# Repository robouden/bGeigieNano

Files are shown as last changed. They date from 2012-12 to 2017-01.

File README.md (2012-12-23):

# Welcome to bGeigie Nano Kit project

This is a lighter version of the bGeigie Mini which is meant to fit in a Pelican Micro Case 1010.

# Requirements
* [Arduino Fio][3]
* [OpenLog][1]
* Adafruit [Ultimate GPS][7]
* [LND-7317][4] geiger pancake with Medcom iRover HV board
* [Monochrome 128x32][2] OLED screen
* 3.7V 1300mAh Lithium battery
* [Pelican 1010][9] micro-case

# Assembly

bGeigieNano

## Pins assignment

| Arduino Fio pin | Target pin |
| :---: | :---: |
| VCC | VCC or Vin pin of the GPS, OpenLog, OLED and iRover (3.3v)|
| GND | GND pin of the GPS, OpenLog, OLED and iRover |
| D2 | pulse pin from the iRover |
| D3 | OLED RST pin |
| D4 | OLED CS pin |
| D5 | OLED DC pin |
| D6 | OLED Data pin |
| D7 | OLED Clk pin |
| D8 | TX pin of the GPS |
| D9 | RX pin of the GPS |
| D10 | TX pin of the OpenLog |
| D11 | RX pin of the OpenLog |
| D12 | GRN pin of the OpenLog |

# Power consumption

* **Fio**: 0.045mA sleep, 6mA at run time
* **OpenLog**: 2mA idle, 6mA at maximum recording rate
* **Adafruit Ultimate GPS**: 25mA acquisition, 20mA tracking
* **Monochrome OLED 128x32 0.91"**: 4mA 50% turn-on, 7.8mA 100% turn-on

## Estimation
The total current used at run time can be estimated around 36mA (= 6+6+20+4) per second which will result in a consumption of 0.01mAh (= 36mA/3600). So
the total log duration if using a battery of 1300mAh will be (1300/.01)/3600 = 36.11 = **36h06m**

## Summary table

| Battery capacity (mAh) | Estimated log duration (days hh:mm) |
| :---: | :---: |
| 1300 | 1d 12:06 |
| 2600 |  3d 00:13 |
| 6600 |  7d 15:19 |

# Build process
## Using the Makefile
    export ARDUINODIR=/home/geigie/arduino-1.0.1/
    export SERIALDEV=/dev/ttyUSB0
    export BOARD=fio
    cp -r libraries /home/geigie/arduino-1.0.1/
    make
    make upload

## Using the prebuilt image
You can use directly the prebuilt image to flash the Arduino Fio. Here is an example with Arduino Fio connected to ttyUSB0:

    /usr/bin/avrdude -DV -p atmega328p -P /dev/ttyUSB0 -c arduino -b 57600 -U flash:w:bGeigieNano.hex:i

# Usage
Once powered on the bGeigieNano will initiliaze a new log file on the SD card, setup the GPS and start counting the CPM.

# Sample log

    # NEW LOG
    # format=1.0.0nano
    $BNRDD,204,2012-09-20T16:53:58Z,776,63,33895,A,5641.7788,N,1411.8820,E,9861.20,A,109,9*46
    $BNRDD,204,2012-09-20T16:54:03Z,771,61,33956,A,5642.2047,N,1412.9433,E,9862.60,A,109,9*4D
    $BNRDD,204,2012-09-20T16:54:08Z,773,70,34026,A,5642.6305,N,1414.0053,E,9865.00,A,109,9*40
    $BNRDD,204,2012-09-20T16:54:13Z,768,59,34085,A,5643.0562,N,1415.0662,E,9866.80,A,108,9*4D
    $BNRDD,204,2012-09-20T16:54:18Z,765,59,34144,A,5643.4820,N,1416.1277,E,9868.10,A,108,9*4D
    $BNRDD,204,2012-09-20T16:54:23Z,776,70,34214,A,5643.9077,N,1417.1884,E,9870.40,A,90,10*4E
    $BNRDD,204,2012-09-20T16:54:28Z,790,69,34283,A,5644.3330,N,1418.2491,E,9871.30,A,90,10*44
    $BNRDD,204,2012-09-20T16:54:33Z,792,77,34360,A,5644.7576,N,1419.3115,E,9871.40,A,90,10*41
    $BNRDD,204,2012-09-20T16:54:38Z,800,73,34433,A,5645.1819,N,1420.3749,E,9872.60,A,90,10*4C
    $BNRDD,204,2012-09-20T16:54:43Z,784,57,34490,A,5645.6060,N,1421.4371,E,9873.10,A,89,10*4A
    $BNRDD,204,2012-09-20T16:54:48Z,787,58,34548,A,5646.0298,N,1422.4998,E,9874.10,A,89,10*40
    $BNRDD,204,2012-09-20T16:54:53Z,792,76,34624,A,5646.4534,N,1423.5620,E,9874.80,A,98,9*73
    $BNRDD,204,2012-09-20T16:54:58Z,804,75,34699,A,5646.8769,N,1424.6242,E,9874.30,A,98,9*74
    $BNRDD,204,2012-09-20T16:55:03Z,808,65,34764,A,5647.3011,N,1425.6873,E,9877.10,A,98,9*7F
    $BNRDD,204,2012-09-20T16:55:08Z,793,55,34819,A,5647.7236,N,1426.7514,E,9876.30,A,89,10*49
    $BNRDD,204,2012-09-20T16:55:13Z,799,65,34884,A,5648.1464,N,1427.8159,E,9876.10,A,98,9*7F
    $BNRDD,204,2012-09-20T16:55:18Z,795,55,34939,A,5648.5688,N,1428.8810,E,9877.80,A,98,9*7B
    $BNRDD,204,2012-09-20T16:55:23Z,774,49,34988,A,5648.9898,N,1429.9472,E,9878.50,A,85,10*46
    $BNRDD,204,2012-09-20T16:55:28Z,768,63,35051,A,5649.4098,N,1431.0137,E,9877.40,A,224,8*4A
    $BNRDD,204,2012-09-20T16:55:33Z,754,63,35114,A,5649.8297,N,1432.0798,E,9876.30,A,223,8*4F
    $BNRDD,204,2012-09-20T16:55:38Z,752,71,35185,A,5650.2496,N,1433.1447,E,9873.20,A,106,9*4C
    $BNRDD,204,2012-09-20T16:55:43Z,753,58,35243,A,5650.6698,N,1434.2092,E,9871.30,A,106,9*40
    $BNRDD,204,2012-09-20T16:55:48Z,765,70,35313,A,5651.0904,N,1435.2737,E,9869.50,A,106,9*4B

# Notes
## OpenLog config

The OpenLog should start listening at 9600bps and in Command mode. Here is the content of the CONFIG.TXT file you have to create on the microSD card:

    9600,26,3,2

## SoftwareSerial update

To make sure all of the NMEA sentences can be received correctly, we will need to update the _SS_MAX_RX_BUFF definition from arduino-1.0.1/libraries/SoftwareSerial/SoftwareSerial.h header file. Here is the modification:

    //#define _SS_MAX_RX_BUFF 64 // RX buffer size -- Old Value is 64
    #define _SS_MAX_RX_BUFF 128 // RX buffer size for TinyGPS

# Licenses
 * [InterruptHandler and bGeigieMini code][5] - Copyright (c) 2011, Robin Scheibler aka FakuFaku
 * [TinyGPS][6] - Copyright (C) 2008-2012 Mikal Hart
 * bGeigieNano - Copyright (c) 2012, Lionel Bergeret
 * [Makefile][8] - Copyright (c) 2012, Tim Marston

  [1]: https://github.com/sparkfun/OpenLog "OpenLog"
  [2]: https://www.adafruit.com/products/661 "Monochrome 128x32 OLED"
  [3]: https://www.sparkfun.com/products/10116 "Arduino Fio"
  [4]: http://www.lndinc.com/products/17/ "LND-7317"
  [5]: https://github.com/fakufaku/SafecastBGeigie-firmware "SafecastBGeigie-firmware"
  [6]: http://arduiniana.org/libraries/tinygps/ "TinyGPS"
  [7]: https://www.adafruit.com/products/746 "Ultimate GPS"
  [8]: http://ed.am/dev/make/arduino-mk "Arduino Makefile"
  [9]: http://www.pelican.com/cases_detail.php?Case=1010 "Pelican 1010"

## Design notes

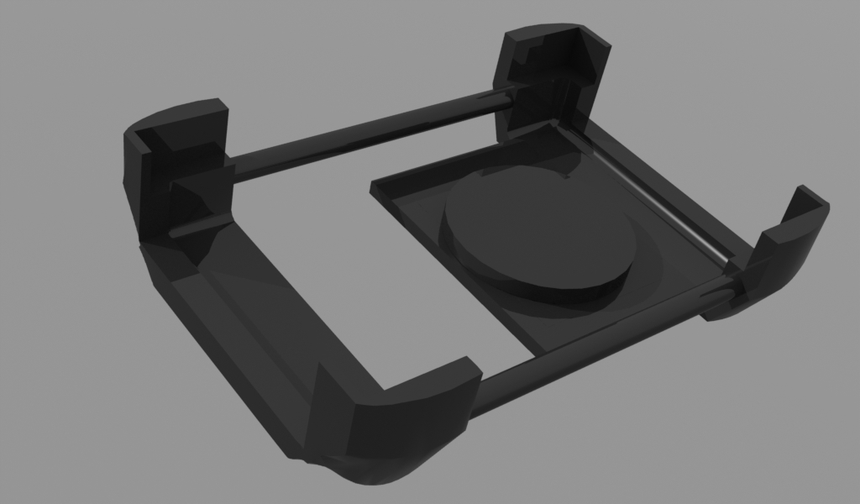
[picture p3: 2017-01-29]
sketchup files/wireless charger.JPG

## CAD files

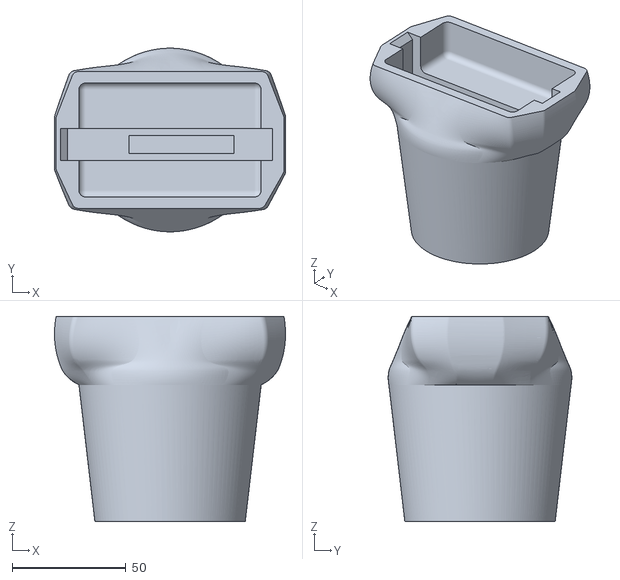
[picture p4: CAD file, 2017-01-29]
sketchup files/PelicanHolder5.stl
101.4 x 80.6 x 90.0

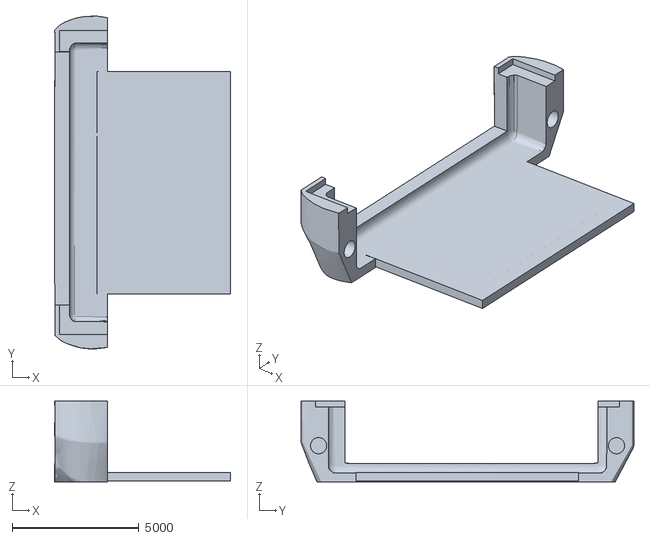
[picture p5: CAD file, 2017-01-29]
sketchup files/wireless charger teensy bgeigie.STL
6935.8 x 13111.0 x 3190.0

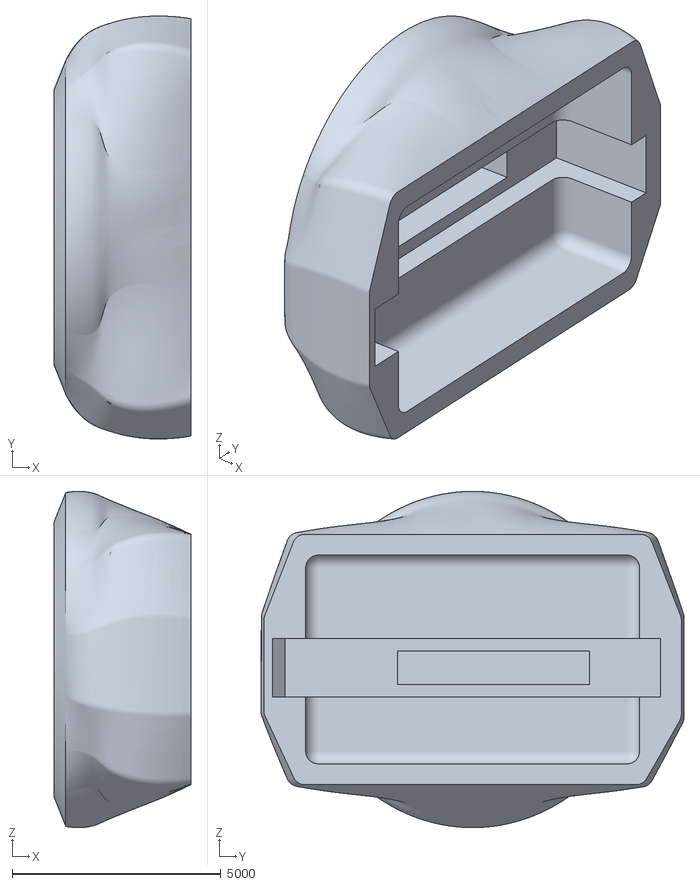
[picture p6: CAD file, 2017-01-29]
sketchup files/cup holder low bottom.STL
3280.0 x 10135.9 x 8058.9

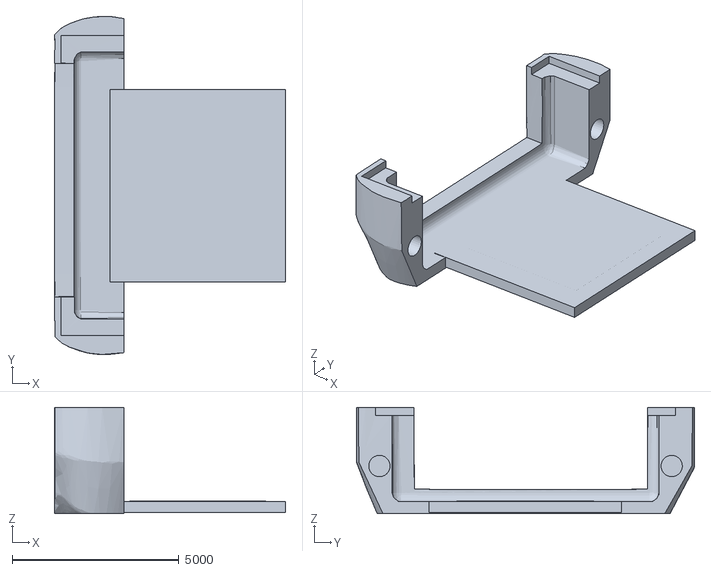
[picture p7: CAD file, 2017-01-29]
sketchup files/cup holder half cut left new.STL
6935.8 x 10131.0 x 3190.0

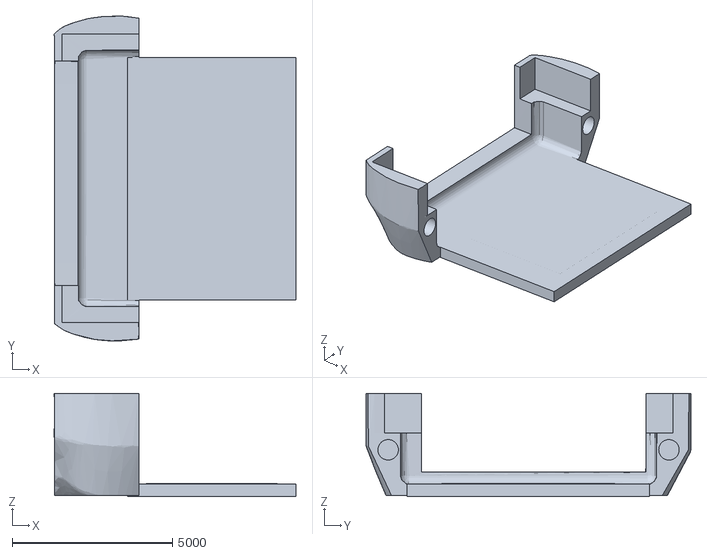
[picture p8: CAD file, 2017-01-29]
sketchup files/cup holder half cut 4.STL
7549.3 x 10131.0 x 3220.0

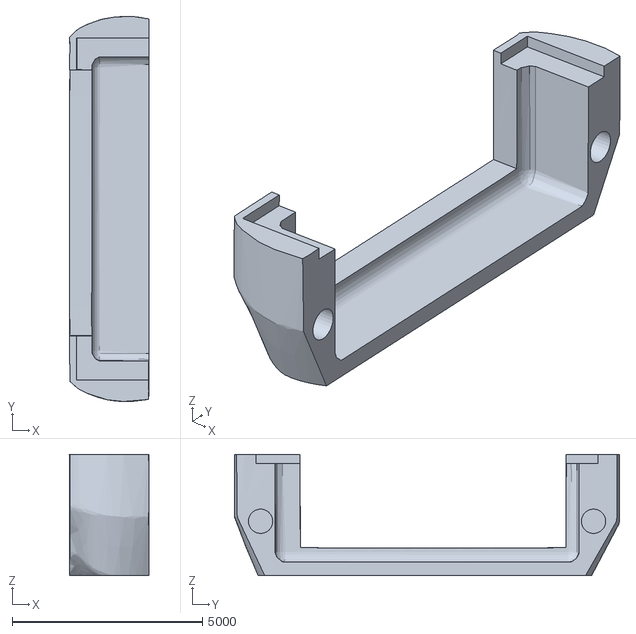
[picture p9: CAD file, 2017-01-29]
sketchup files/cup holder half cut 5.STL
2093.1 x 10131.0 x 3190.0

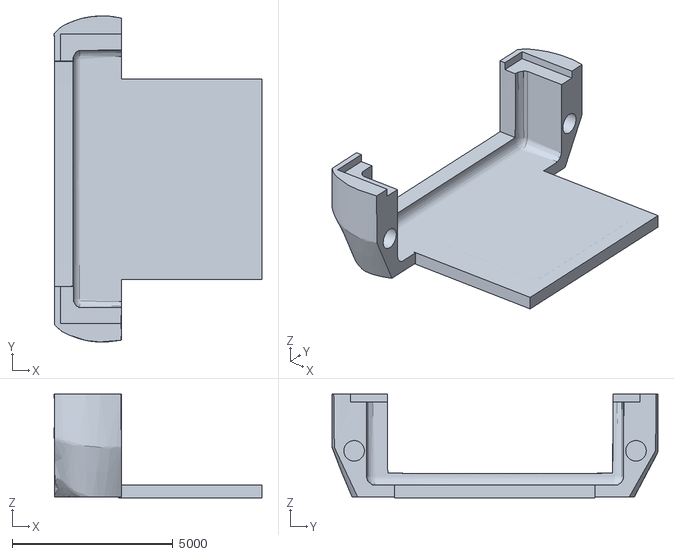
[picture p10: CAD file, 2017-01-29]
sketchup files/cup holder half cut 6.STL
6462.7 x 10131.0 x 3220.0

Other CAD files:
sketchup files/cup holder half cut.STL
sketchup files/cup holder.STL
sketchup files/Wireless charger EJ.skp
sketchup files/Wireless charger EJ~.skp
sketchup files/cup holder.obj

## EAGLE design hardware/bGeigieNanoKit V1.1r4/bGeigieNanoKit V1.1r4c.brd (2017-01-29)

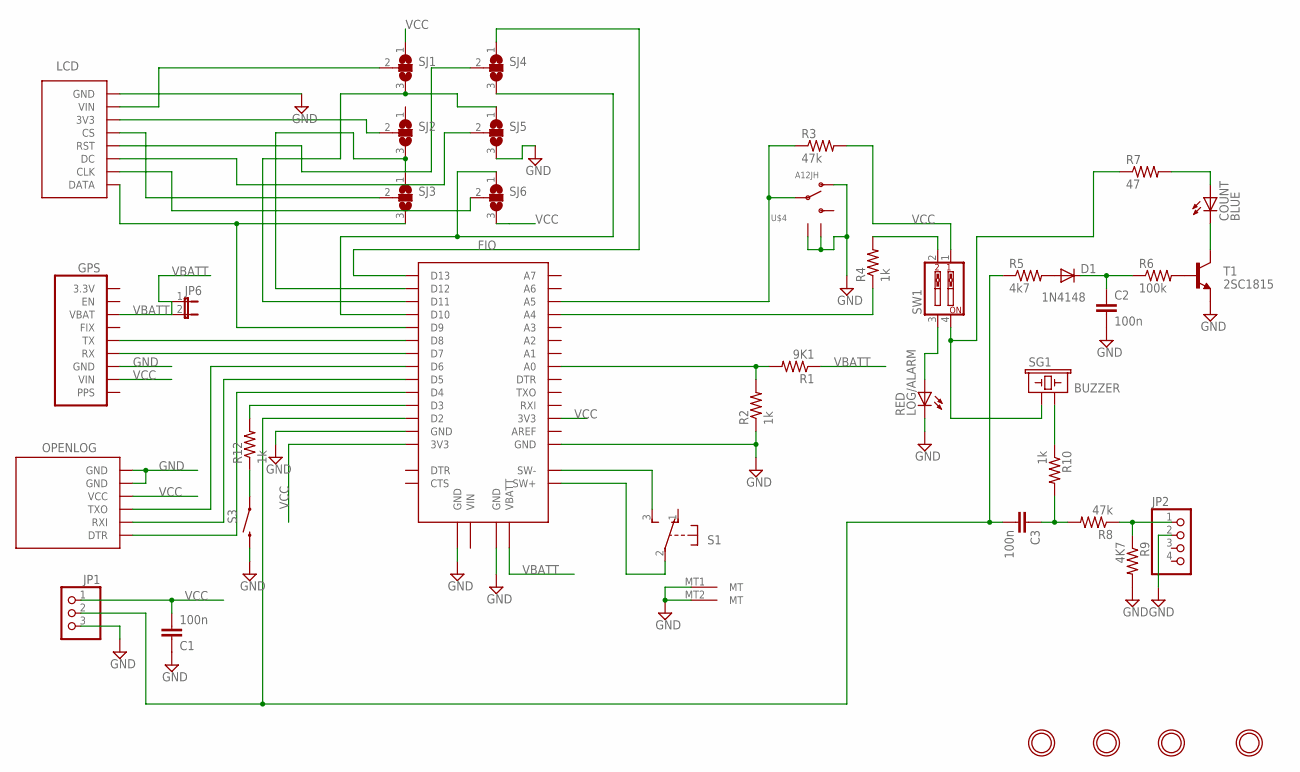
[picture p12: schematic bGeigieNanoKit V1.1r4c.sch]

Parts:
C1, C2, C3: 100n; C025-024X044
COUNT: BLUE; LED3MM
D1: 1N4148; DO35-7
FIO: FIO_SOCKETBOT; FIO_V23_SOCKET_BOT
GPS: ULTIMATE_GPSTOP; ULTIMATE_GPS_V3_TOP
JP1: PINHD-1X3/90; 1X03/90
JP2: HEADER-1X4ROUND; 1X04_ROUND
JP6: JUMPER-2SMD-NC; SJ_2S
LCD: SSD1306_128X64_V2_LCD1.3IN_LEVER; SSD1306_128X64_1.3IN_LCD_LEVER
LOG/ALARM: RED; LED3MM
OPENLOG: OPENLOG
R1: 9K1; 0207/10
R2, R4, R10, R12: 1k; 0207/10
R3, R8: 47k; 0207/10
R5: 4k7; 0207/10
R6: 100k; 0207/10
R7: 47; 0207/10
R9: 4K7; 0207/10
S1: S1; EG1206
S3: SWITCH-MOMENTARY-2PTH; TACTILE-PTH
SG1: BUZZER; BUZZER-12MM
SJ1, SJ2, SJ3, SJ4, SJ5, SJ6: SJ2W; SJ_2
SW1: SW_DIP-2; EDG-02
T1: 2SC1815; TO92-ECB
U$4: A12JH; A12AH
U$6, U$7, U$8, U$9: MOUNTINGHOLE3.0THIN; MOUNTINGHOLE_3.0_PLATEDTHIN

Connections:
GND: C1.1, C2.2, FIO.JP1$2 (GND), FIO.JP2$1 (GND), FIO.JP5$1 (GND), FIO.JP6$1 (GND), GPS.JP1$3 (GND), GPS.U$8$P$1 (GND), GPS.U$9$P$1 (GND), JP1.3, JP2.2, LCD.JP1$8 (GND), LCD.U$23$P$1 (GND), LCD.U$26$P$1 (GND), LOG/ALARM.K (C), OPENLOG.JP1$5 (GND), OPENLOG.JP1$6 (GND), R2.1, R9.2, S1.MT1 (MT), S1.MT2 (MT), S3.3 (2), SJ5.3, T1.E, U$4.P$1, U$4.P$4 (GND), U$4.P$5 (GND)
unnamed: FIO.JP1$10 (D9), LCD.JP1$1 (DATA), SJ3.3
unnamed: FIO.JP1$11 (D10), SJ4.3, SJ6.1
unnamed: FIO.JP1$12 (D11), SJ1.3, SJ5.1
unnamed: FIO.JP1$13 (D12), SJ2.3, SJ3.1
unnamed: FIO.JP1$14 (D13), SJ4.1
unnamed: FIO.JP1$9 (D8), GPS.JP1$5 (TX)
unnamed: FIO.JP1$8 (D7), GPS.JP1$4 (RX)
unnamed: FIO.JP1$7 (D6), OPENLOG.JP1$3 (TXO)
unnamed: FIO.JP1$6 (D5), OPENLOG.JP1$2 (RXI)
unnamed: FIO.JP1$5 (D4), OPENLOG.JP1$1 (DTR)
unnamed: FIO.JP5$7 (A0), R1.2, R2.2
unnamed: FIO.JP7$2 (SW+), S1.2
unnamed: FIO.JP7$1 (SW-), S1.3 (S)
unnamed: FIO.JP5$12 (A5), R3.1, U$4.P$2
unnamed: LOG/ALARM.A, SW1.3
unnamed: R4.2, SW1.2
unnamed: C3.2, FIO.JP1$3 (D2), JP1.2, R5.1
unnamed: COUNT.A, R7.2
unnamed: R12.1, S3.1
unnamed: COUNT.K (C), T1.C
unnamed: R10.1, SG1.- (2)
unnamed: C3.1, R8.2, R10.2
unnamed: JP2.1, R8.1, R9.1
unnamed: D1.A, R5.2
unnamed: C2.1, D1.C, R6.1
unnamed: R6.2, T1.B
unnamed: FIO.JP1$4 (D3), R12.2
unnamed: LCD.JP1$7 (VIN), SJ1.2
unnamed: R7.1, SG1.+ (1), SW1.4
unnamed: FIO.JP5$11 (A4), R4.1
unnamed: LCD.JP1$6 (3V3), SJ2.2
unnamed: LCD.JP1$5 (CS), SJ3.2
unnamed: LCD.JP1$4 (RST), SJ4.2
unnamed: LCD.JP1$3 (DC), SJ5.2
unnamed: LCD.JP1$2 (CLK), SJ6.2
VBATT: FIO.JP2$2 (VBATT), GPS.JP1$7 (VBAT), JP6.1, JP6.2, R1.1
VCC: C1.2, FIO.JP1$1 (3V3), FIO.JP5$3 (3V3), GPS.JP1$2 (VIN), JP1.1, OPENLOG.JP1$4 (VCC), R3.2, SJ1.1, SJ6.3, SW1.1

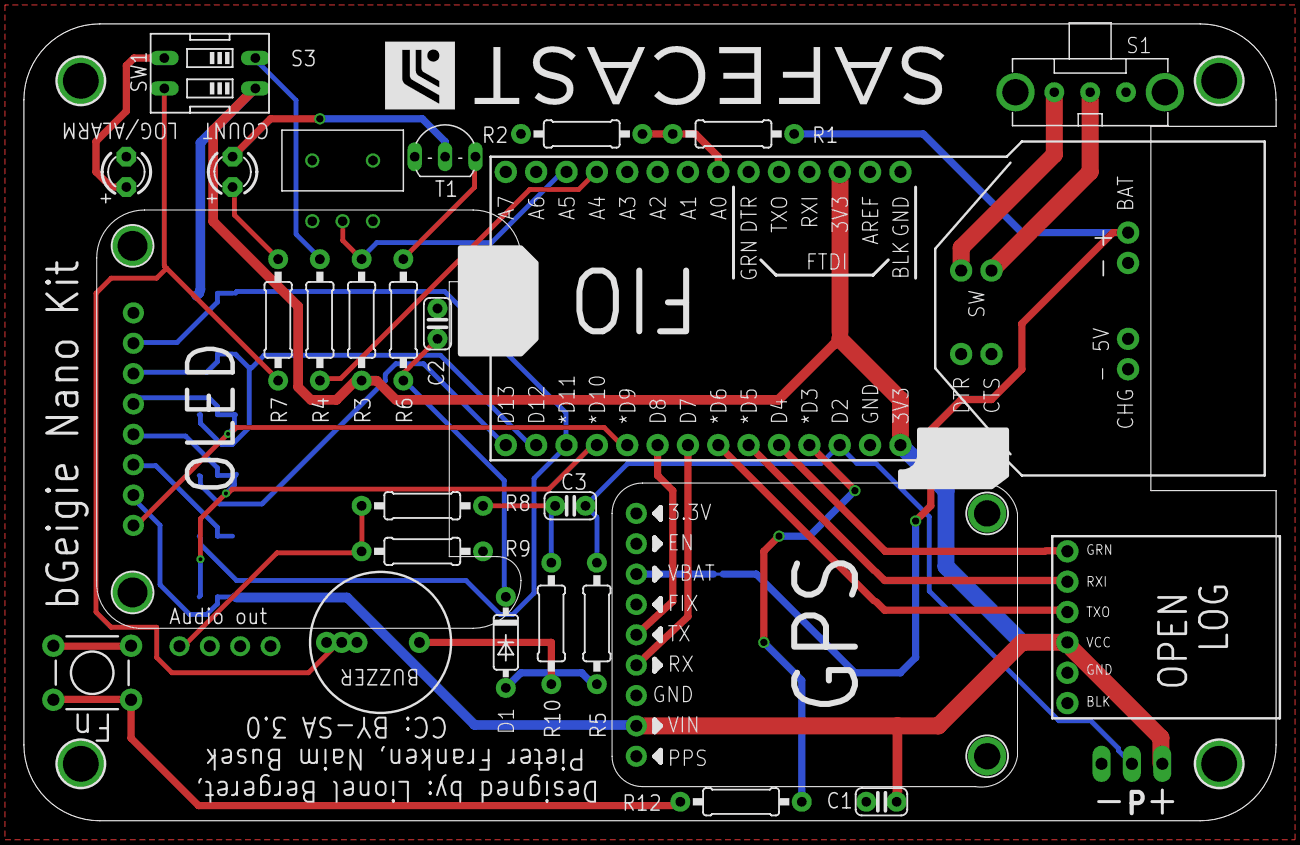
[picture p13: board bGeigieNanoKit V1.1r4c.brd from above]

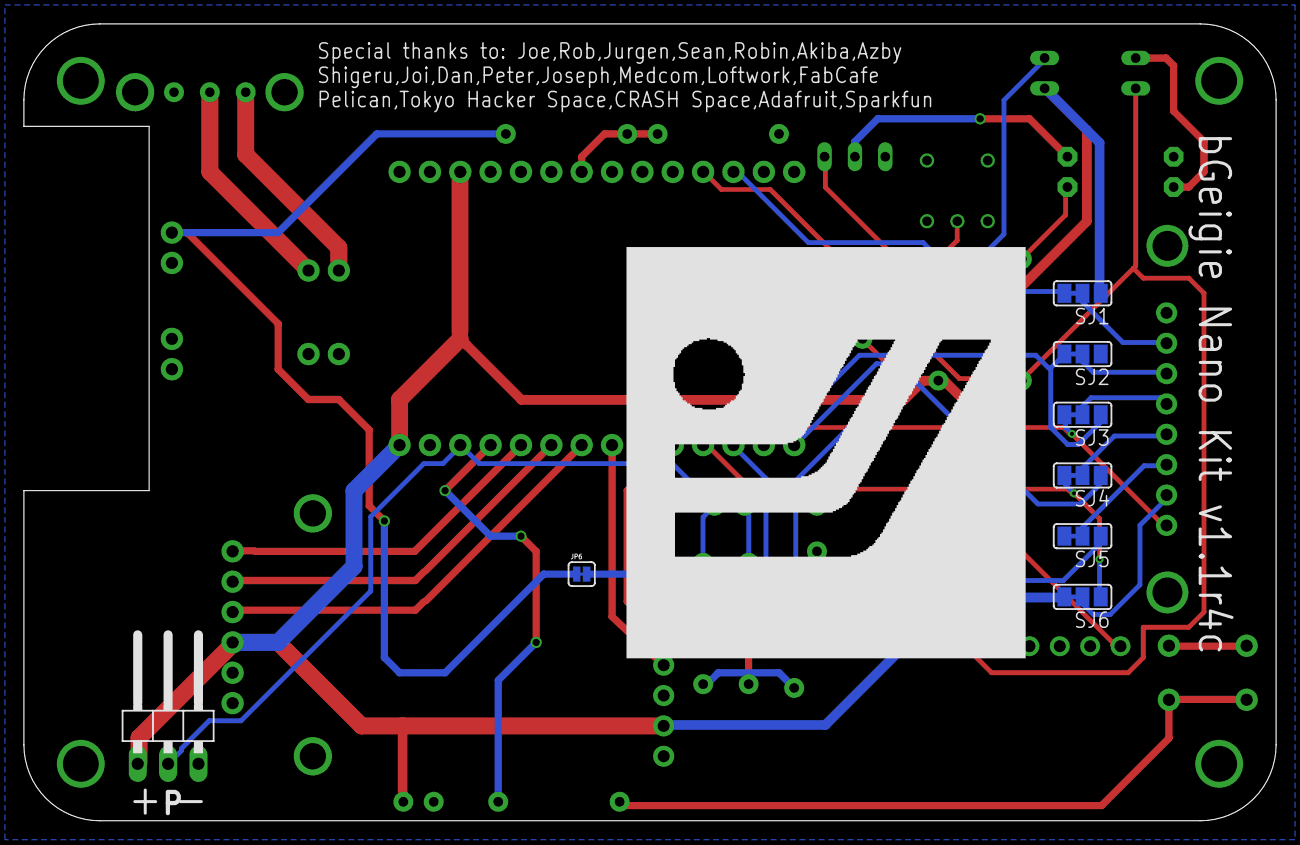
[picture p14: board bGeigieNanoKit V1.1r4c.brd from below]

Board: 2 copper layers, 104.8 x 66.7 mm, 42 parts (10 on the bottom side), 38 nets.

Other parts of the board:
U$1: SAFECAST_LOGO4
U$5: SAFECAST_LOGO2

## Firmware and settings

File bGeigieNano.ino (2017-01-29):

/*
   The bGeigie-nano
   A device for car-borne radiation measurement (aka Radiation War-driving).

   Copyright (c) 2012, Lionel Bergeret
   Copyright (c) 2011, Robin Scheibler aka FakuFaku, Christopher Wang aka Akiba
   All rights reserved.

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
   THIS SOFTWARE IS PROVIDED BY THE COPYRIGHT HOLDERS AND CONTRIBUTORS "AS IS" AND
   ANY EXPRESS OR IMPLIED WARRANTIES, INCLUDING, BUT NOT LIMITED TO, THE IMPLIED
   WARRANTIES OF MERCHANTABILITY AND FITNESS FOR A PARTICULAR PURPOSE ARE
   DISCLAIMED. IN NO EVENT SHALL <COPYRIGHT HOLDER> BE LIABLE FOR ANY
   DIRECT, INDIRECT, INCIDENTAL, SPECIAL, EXEMPLARY, OR CONSEQUENTIAL DAMAGES
   (INCLUDING, BUT NOT LIMITED TO, PROCUREMENT OF SUBSTITUTE GOODS OR SERVICES;
   LOSS OF USE, DATA, OR PROFITS; OR BUSINESS INTERRUPTION) HOWEVER CAUSED AND
   ON ANY THEORY OF LIABILITY, WHETHER IN CONTRACT, STRICT LIABILITY, OR TORT
   (INCLUDING NEGLIGENCE OR OTHERWISE) ARISING IN ANY WAY OUT OF THE USE OF THIS
   SOFTWARE, EVEN IF ADVISED OF THE POSSIBILITY OF SUCH DAMAGE.
*/

#include <limits.h>
#include <SoftwareSerial.h>
#include <math.h>
#include <stdlib.h>
#include <avr/wdt.h>
#include <EEPROM.h>
#include "TinyGPS.h"

#include "NanoSetup.h"
#include "NanoConfig.h"
#include "NanoDebug.h"

// OLED settings --------------------------------------------------------------
#if ENABLE_SSD1306
#include <Wire.h>
#include <Adafruit_GFX.h>
#include <Adafruit_SSD1306.h>

#ifdef OLED_SPI_MODE
Adafruit_SSD1306 display(OLED_DATA, OLED_CLK, OLED_DC, OLED_RESET, OLED_CS);
#else
Adafruit_SSD1306 display(OLED_RESET);
#endif

#if (SSD1306_LCDHEIGHT != 32)
#error("Height incorrect, please fix Adafruit_SSD1306.h!");
#endif

// For distance computation
bool gps_fix_first = true;
float gps_last_lon = 0, gps_last_lat = 0;
unsigned long int gps_distance = 0;
#endif

// Geiger settings ------------------------------------------------------------
#define TIME_INTERVAL 5000
#define LINE_SZ 100
#define BUFFER_SZ 12
#define STRBUFFER_SZ 32
#define NX 12
#define AVAILABLE 'A'  // indicates geiger data are ready (available)
#define VOID      'V'  // indicates geiger data not ready (void)

// log file headers
#define LOGFILE_HEADER "# NEW LOG\n# format="
char logfile_name[13];  // placeholder for filename
bool logfile_ready = false;

// geiger statistics
unsigned long shift_reg[NX] = {0};
unsigned long reg_index = 0;
unsigned long total_count = 0;
unsigned long max_count = 0;
unsigned long uptime = 0;
int str_count = 0;
char geiger_status = VOID;

// the line buffer for serial receive and send
static char line[LINE_SZ];
static char strbuffer[STRBUFFER_SZ];

// Pulse counter --------------------------------------------------------------
#if ENABLE_HARDWARE_COUNTER
// Hardware counter
#include "HardwareCounter.h"
HardwareCounter hwc(HARDWARE_COUNTER_TIMER1, TIME_INTERVAL);
#else
// Interrupt counter
#include "InterruptCounter.h"
#endif

#if ENABLE_HARDWARE_COUNTER
#if ENABLE_SLEEPMODE
#define IS_READY (1)
#else
#define IS_READY (hwc.available())
#endif
#else
#define IS_READY (interruptCounterAvailable())
#endif

// OpenLog settings -----------------------------------------------------------
#if ENABLE_OPENLOG
#define OPENLOG_RETRY 200
SoftwareSerial OpenLog(OPENLOG_RX_PIN, OPENLOG_TX_PIN);
static const int resetOpenLog = OPENLOG_RST_PIN;
#endif
bool openlog_ready = false;

// Gps settings ------------------------------------------------------------
TinyGPS gps(true);
#define GPS_INTERVAL 1000
char gps_status = VOID;

#if ENABLE_SOFTGPS
SoftwareSerial gpsSerial(GPS_RX_PIN, GPS_TX_PIN);
#endif

// Gps data buffers
static char lat[BUFFER_SZ];
static char lon[BUFFER_SZ];

// MTK33x9 chipset
#define PMTK_SET_NMEA_UPDATE_1HZ "$PMTK220,1000*1F"
#define PMTK_SET_NMEA_OUTPUT_ALLDATA "$PMTK314,1,1,1,1,1,1,0,0,0,0,0,0,0,0,0,0,0,0,0*28"
#define PMTK_SET_NMEA_OUTPUT_RMCGGA "$PMTK314,0,1,0,1,0,0,0,0,0,0,0,0,0,0,0,0,0,0,0*28"
#define SBAS_ENABLE "$PMTK313,1*2E\r\n"
#define DGPS_WAAS_ON "$PMTK301,2*2E\r\n"

#if ENABLE_STATIC_GPS
#include <avr/pgmspace.h>
// GPS test sentences
char strGPRMC[] PROGMEM = "$GPRMC,201547.000,A,3014.5527,N,09749.5808,W,0.24,163.05,040109,,*1A";
char strGPGGA[] PROGMEM = "$GPGGA,201548.000,3014.5529,N,09749.5808,W,1,07,1.5,225.6,M,-22.5,M,18.8,0000*78";
char *teststrs[2] = {strGPRMC, strGPGGA};

static void sendstring(TinyGPS &gps, const PROGMEM char *str)
{
  while (true)
  {
    char c = pgm_read_byte_near(str++);
    if (!c) break;
    gps.encode(c);
  }
  gps.encode('\r');
  gps.encode('\n');
}
#endif

// Function definitions ---------------------------------------------------------
// Atmel Tips and Tricks: 3.6 Tip #6 – Access types: Static
static unsigned long cpm_gen();
static bool gps_gen_filename(TinyGPS &gps, char *buf);
static bool gps_gen_timestamp(TinyGPS &gps, char *buf, unsigned long counts, unsigned long cpm, unsigned long cpb);
static char checksum(char *s, int N);
#if ENABLE_OPENLOG
static void setupOpenLog();
static bool loadConfig(char *fileName);
static void createFile(char *fileName);
#endif
static void gps_program_settings();
static float read_voltage(int pin);
static int availableMemory();
static unsigned long elapsedTime(unsigned long startTime);
#if ENABLE_100M_TRUNCATION
static void truncate_100m(char *latitude, char *longitude);
#endif

// Sleep mode -----------------------------------------------------------------
#if ENABLE_SLEEPMODE
#include <avr/sleep.h>
#include <avr/power.h>

volatile int f_wdt=1;

ISR(WDT_vect)
{
  if(f_wdt == 0)
  {
    f_wdt=1;
  }
  else
  {
    DEBUG_PRINTLN("WARNING: WDT Overrun");
  }
}

void enableSleepTimer(void)
{
  cli();
  wdt_reset();

  // Setup WDT
  // Clear the reset flag
  MCUSR &= ~(1<<WDRF);

  // Set WDCE (4 clock cycles updates)
  WDTCSR |= (1<<WDCE) | (1<<WDE);

  // Set new watchdog timeout prescaler value
  WDTCSR = 1<<WDP3; // 4.0 seconds

  // Enable the WD interrupt
  WDTCSR |= _BV(WDIE);

  sei();
}

void disableSleepTimer(void)
{
  cli();
  wdt_reset();

  // Setup WDT
  // Clear the reset flag
  MCUSR &= ~(1<<WDRF);

  // Keep old prescaler setting to prevent unintentional time-out
  WDTCSR |= (1<<WDCE) | (1<<WDE);

  // Disable the WD interrupt
  WDTCSR |= 0x00;

  sei();
}

void enterSleep(void)
{
  power_all_disable();
  set_sleep_mode(SLEEP_MODE_STANDBY); // keep oscillator active

  // Enable and enter sleep mode
  sleep_enable();
  sleep_mode();

  // The program will continue from here after the WDT timeout

  // Disable sleep and re-enable the peripherals
  sleep_disable();
  power_all_enable();
}
#endif

// Nano Settings --------------------------------------------------------------
static ConfigType config;
static DoseType dose;
NanoSetup nanoSetup(OpenLog, config, dose, line, LINE_SZ);

// ****************************************************************************
// Setup
// ****************************************************************************
void setup()
{
  pinMode(GPS_LED_PIN, OUTPUT);
  pinMode(GEIGIE_TYPE_PIN, INPUT);

  Serial.begin(9600);

#ifndef ENABLE_SLEEPMODE
  // enable and reset the watchdog timer
  wdt_enable(WDTO_8S);
  wdt_reset();
#endif

  // Load EEPROM settings
  nanoSetup.initialize();

#if ENABLE_OPENLOG
  DEBUG_PRINTLN("Initializing OpenLog.");
  OpenLog.begin(9600);
  setupOpenLog();
  if (openlog_ready) {
    nanoSetup.loadFromFile("SAFECAST.TXT");
  }
#endif

  DEBUG_PRINTLN("Initializing pulse counter.");

#if ENABLE_HARDWARE_COUNTER
  // Start the Pulse Counter!
  hwc.start();
#else
  // Create pulse counter
  interruptCounterSetup(INTERRUPT_COUNTER_PIN, TIME_INTERVAL);

  // And now Start the Pulse Counter!
  interruptCounterReset();
#endif

#if ENABLE_SOFTGPS
  DEBUG_PRINTLN("Initializing GPS.");
  gpsSerial.begin(9600);

  // Put GPS serial in listen mode
  gpsSerial.listen();

  // initialize and program the GPS module
  gps_program_settings();
#endif

  DEBUG_PRINT("Devide id = ");
  DEBUG_PRINTLN(config.device_id);

#if ENABLE_EEPROM_DOSE
  EEPROM_readAnything(BMRDD_EEPROM_DOSE, dose);
  if (dose.total_time != 0) {
    dtostrf((float)( ((dose.total_count/(dose.total_time/60.0))/config.cpm_factor) * (dose.total_time/3600.0) ), 0, 2, strbuffer);
    DEBUG_PRINT("Total dose = ");
    DEBUG_PRINT(strbuffer);
    DEBUG_PRINTLN(" uSv");
  } else {
    DEBUG_PRINTLN("Total dose = 0.00 uSv");
  }
#endif

  // setup analog reference to read battery and boost voltage
  analogReference(INTERNAL);

#if ENABLE_SLEEPMODE
  enableSleepTimer();
#endif

#if ENABLE_SSD1306
  display.begin(SSD1306_SWITCHCAPVCC, 0x3C);

  // show splashscreen logo
  display.display();

  delay(1000);

  // show 2nd splashscreen
  display.clearDisplay();

  display.setTextColor(WHITE);
  display.setTextSize(1);
  sprintf_P(strbuffer, PSTR("Geigie Nano %s"), NANO_VERSION);
  display.setCursor((128-((strlen(strbuffer)+1)*6))/2, 0);
  if (config.type == GEIGIE_TYPE_B) {
    display.print("b");
  } else {
    display.print("x");
  }
  display.print(strbuffer);

  display.setTextSize(2);
  display.setCursor(40, 8);
  sprintf_P(strbuffer, PSTR("#%04d"), config.device_id);
  display.print(strbuffer);

  display.setTextSize(1);
  if (strlen(config.user_name)) {
    display.setCursor((128-(strlen(config.user_name)*6))/2, 24); // textsize*8
    display.print(config.user_name);
  }
  display.display();
#endif

  Serial.println(availableMemory());

  DEBUG_PRINTLN("Setup completed.");
}

// ****************************************************************************
// Main loop
// ****************************************************************************
void loop()
{
  bool gpsReady = false;

#if ENABLE_GEIGIE_SWITCH
  // Check geigie mode switch
  if (analogRead(GEIGIE_TYPE_PIN) > GEIGIE_TYPE_THRESHOLD) {
    config.type = GEIGIE_TYPE_X; // xGeigie
  } else {
    config.type = GEIGIE_TYPE_B; // bGeigie
  }
#endif

#if ENABLE_SLEEPMODE
  if(f_wdt == 1)
  {
    disableSleepTimer();
#endif

#if ENABLE_SOFTGPS
  // Put GPS serial in listen mode
  gpsSerial.listen();
#endif

  // For one second we parse GPS sentences
  for (unsigned long start = millis(); (elapsedTime(start) < GPS_INTERVAL) and !IS_READY;)
  {
#if ENABLE_STATIC_GPS
    for (int i=0; i<2; ++i)
    {
      sendstring(gps, teststrs[i]);
    }
#else
#if ENABLE_SOFTGPS
    while (gpsSerial.available())
    {
      char c = gpsSerial.read();
#else
    while (Serial.available())
    {
      char c = Serial.read();
#endif

#if ENABLE_GPS_NMEA_LOG
      Serial.print(c); // uncomment this line if you want to see the GPS data flowing
#endif
      if (gps.encode(c)) // Did a new valid sentence come in?
        gpsReady = true;
    }
#endif
  }

#if ENABLE_SLEEPMODE
  // Will wakeup in 4 seconds from now
  enableSleepTimer();
#endif

  if ((gpsReady) || (gps_status == AVAILABLE)) {
    digitalWrite(GPS_LED_PIN, HIGH);
  } else {
    digitalWrite(GPS_LED_PIN, LOW);
  }

  // generate CPM every TIME_INTERVAL seconds
  if IS_READY {
      unsigned long cpm=0, cpb=0;

#ifndef ENABLE_SLEEPMODE
      // first, reset the watchdog timer
      wdt_reset();
#endif

#if ENABLE_HARDWARE_COUNTER
      // obtain the count in the last bin
      cpb = hwc.count();

      // reset the pulse counter
      hwc.start();
#else
      // obtain the count in the last bin
      cpb = interruptCounterCount();

      // reset the pulse counter
      interruptCounterReset();
#endif

      // insert count in sliding window and compute CPM
      shift_reg[reg_index] = cpb;     // put the count in the correct bin
      reg_index = (reg_index+1) % NX; // increment register index
      cpm = cpm_gen();                // compute sum over all bins

      // update the total counter
      total_count += cpb;
      uptime += 5;

      // update max cpm
      if (cpm > max_count) max_count = cpm;

#if ENABLE_EEPROM_DOSE
      dose.total_count += cpb;
      dose.total_time += 5;
      if (dose.total_time % BMRDD_EEPROM_DOSE_WRITETIME == 0) {
         EEPROM_writeAnything(BMRDD_EEPROM_DOSE, dose);
      }
#endif

      // set status of Geiger
      if (str_count < NX)
      {
        geiger_status = VOID;
        str_count++;
      } else if (cpm == 0) {
        geiger_status = VOID;
      } else {
        geiger_status = AVAILABLE;
      }

#if ENABLE_WAIT_GPS_FOR_LOG
      if ((!logfile_ready) && (gps_status == AVAILABLE))
#else
      if (!logfile_ready)
#endif
      {
         if (gps_gen_filename(gps, logfile_name)) {
           logfile_ready = true;

#if ENABLE_OPENLOG
           DEBUG_PRINTLN("Create new logfile.");
           createFile(logfile_name);
           // print header to serial
           sprintf_P(strbuffer, PSTR(LOGFILE_HEADER));
           OpenLog.print(strbuffer);
           DEBUG_PRINT(strbuffer);
           sprintf_P(strbuffer, PSTR(NANO_VERSION));
           OpenLog.print(strbuffer);
           DEBUG_PRINT(strbuffer);

#ifdef ENABLE_LND_DEADTIME
           sprintf_P(strbuffer, PSTR("nano\n# deadtime=on\n"));
#else
           sprintf_P(strbuffer, PSTR("nano\n));
#endif
           OpenLog.print(strbuffer);
           DEBUG_PRINT(strbuffer);

           // Settings dump
           sprintf_P(line, PSTR("# nm=%s,tz=%d,cn=%s,cpmf=%d,st=%d,ss=%d,sh=%d,sm=%d\n"),
               config.user_name,
               config.timezone,
               config.country_code,
               (int)config.cpm_factor,
               config.sensor_type,
               config.sensor_shield,
               config.sensor_height,
               config.sensor_mode);
           OpenLog.print(line);
           Serial.print(line);
#endif
         }
      }

      // generate timestamp. only update the start time if
      // we printed the timestamp. otherwise, the GPS is still
      // updating so wait until its finished and generate timestamp
      memset(line, 0, LINE_SZ);
      gps_gen_timestamp(gps, line, shift_reg[reg_index], cpm, cpb);

      // Printout line
      Serial.println(line);

#if ENABLE_OPENLOG
      if ((logfile_ready) && (GEIGIE_TYPE_B == config.type)) {
        // Put OpenLog serial in listen mode
        OpenLog.listen();
        OpenLog.println(line);

#if ENABLE_DIAGNOSTIC
        dtostrf(read_voltage(VOLTAGE_PIN), 0, 1, strbuffer);
        OpenLog.print("$DIAG,");
        OpenLog.println(strbuffer);
#endif
      }
#endif
  }

#if ENABLE_SLEEPMODE
    // Leave some time to serial to flush data
    delay(100);

    // Clear the flag
    f_wdt = 0;

    // Re-enter sleep mode
    enterSleep();
  }
#endif

}

// ****************************************************************************
// Utility functions
// ****************************************************************************

/* calculate elapsed time. this takes into account rollover */
unsigned long elapsedTime(unsigned long startTime) {
  unsigned long stopTime = millis();

  if (startTime >= stopTime) {
    return startTime - stopTime;
  } else {
    return (ULONG_MAX - (startTime - stopTime));
  }
}

#if ENABLE_OPENLOG
/* wait for openlog prompt */
bool waitOpenLog(bool commandMode) {
  int safeguard = 0;
  bool result = false;

  while(safeguard < OPENLOG_RETRY) {
    safeguard++;
    if(OpenLog.available())
      if(OpenLog.read() == (commandMode ? '>':'<')) break;
    delay(10);
  }

  if (safeguard >= OPENLOG_RETRY) {
    DEBUG_PRINTLN("OpenLog init failed ! Check if the CONFIG.TXT is set to 9600,26,3,2");
  } else {
    DEBUG_PRINTLN(" - ready");
    result = true;
  }

  return result;
}

/* setups up the software serial, resets OpenLog */
void setupOpenLog() {
  pinMode(resetOpenLog, OUTPUT);
  OpenLog.listen();

  // reset OpenLog
  DEBUG_PRINTLN(" - reset");
  digitalWrite(resetOpenLog, LOW);
  delay(100);
  digitalWrite(resetOpenLog, HIGH);

  if (!waitOpenLog(true)) {
    logfile_ready = true;
  } else {
    openlog_ready = true;
  }
}

/* create a new file */
void createFile(char *fileName) {
  int result = 0;
  int safeguard = 0;

  OpenLog.listen();

  do {
    result = 0;

    do {
#ifndef ENABLE_SLEEPMODE
      // reset the watchdog timer
      wdt_reset();
#endif

      DEBUG_PRINT(" - append ");
      DEBUG_PRINTLN(fileName);

      OpenLog.print("append ");
      OpenLog.print(fileName);
      OpenLog.write(13); //This is \r

      // wait for OpenLog to indicate file is open and ready for writing
      DEBUG_PRINTLN(" - wait");
      if (!waitOpenLog(false)) {
        DEBUG_PRINTLN("Append file failed");
        break;
      }
      result = 1;
    } while (0);

    if (0 == result) {
      // reset OpenLog
      DEBUG_PRINTLN(" - reset");
      digitalWrite(resetOpenLog, LOW);
      delay(100);
      digitalWrite(resetOpenLog, HIGH);

      // Wait for OpenLog to return to waiting for a command
      waitOpenLog(true);
    }
  } while (0 == result);

  //OpenLog is now waiting for characters and will record them to the new file
}
#endif

/* compute check sum of N bytes in array s */
char checksum(char *s, int N)
{
  int i = 0;
  char chk = s[0];

  for (i=1 ; i < N ; i++)
    chk ^= s[i];

  return chk;
}

/* compute cpm */
unsigned long cpm_gen()
{
   unsigned int i;
   unsigned long c_p_m = 0;

   // sum up
   for (i=0 ; i < NX ; i++)
     c_p_m += shift_reg[i];

#ifdef ENABLE_LND_DEADTIME
   // deadtime compensation (medcom international)
   c_p_m = (unsigned long)((float)c_p_m/(1-(((float)c_p_m*1.8833e-6))));
#endif

   return c_p_m;
}

/* generate log filename */
bool gps_gen_filename(TinyGPS &gps, char *buf) {
  int year = 2012;
  byte month = 0, day = 0, hour = 0, minute = 0, second = 0, hundredths = 0;
  unsigned long age;

  gps.crack_datetime(&year, &month, &day, &hour, &minute, &second, &hundredths, &age);
  if (TinyGPS::GPS_INVALID_AGE == age) {
    return false;
  }

  // Create the filename for that drive
  sprintf_P(buf, PSTR("%04d%02d%02d.log"),config.device_id, month, day);

  return true;
}

/* convert long integer from TinyGPS to string "xxxxx.xxxx" */
void get_coordinate_string(bool is_latitude, unsigned long val, char *buf)
{
  unsigned long left = 0;
  unsigned long right = 0;

  left = val/100000.0;
  right = (val - left*100000)/10;
  if (is_latitude) {
    sprintf_P(buf, PSTR("%04ld.%04ld"), left, right);
  } else {
    sprintf_P(buf, PSTR("%05ld.%04ld"), left, right);
  }
}

/* convert long integer from TinyGPS to float WGS84 degrees */
float get_wgs84_coordinate(unsigned long val)
{
  double result = 0.0;
  result = val/10000000.0;
  result = ((result-(int)result)/60.0)*100 + (int)result;
  return (float)result;
}

/* generate log result line */
bool gps_gen_timestamp(TinyGPS &gps, char *buf, unsigned long counts, unsigned long cpm, unsigned long cpb)
{
  int year = 2012;
  byte month = 0, day = 0, hour = 0, minute = 0, second = 0, hundredths = 0;
  long int x = 0, y = 0;
  float faltitude = 0, fspeed = 0;
  unsigned short nbsat = 0;
  unsigned long precission = 0;
  unsigned long age;
  byte len, chk;
  char NS = 'N';
  char WE = 'E';
  static int toggle = 0;

  memset(lat, 0, BUFFER_SZ);
  memset(lon, 0, BUFFER_SZ);
  memset(strbuffer, 0, STRBUFFER_SZ);

  // get GPS date
  gps.crack_datetime(&year, &month, &day, &hour, &minute, &second, &hundredths, &age);
  if (TinyGPS::GPS_INVALID_AGE == age) {
    year = 2012, month = 0, day = 0, hour = 0, minute = 0, second = 0, hundredths = 0;
  }

  // get GPS position, altitude and speed
  gps.get_position(&x, &y, &age);
  if (!gps.status()) {
    gps_status = VOID;
  } else {
    gps_status = AVAILABLE;
  }
  faltitude = gps.f_altitude();
  fspeed = gps.f_speed_kmph();
  nbsat = gps.satellites();
  precission = gps.hdop();

  if (x < 0) { NS = 'S'; x = -x;}
  if (y < 0) { WE = 'W'; y = -y;}
  get_coordinate_string(true, x == TinyGPS::GPS_INVALID_ANGLE ? 0 : x, lat);
  get_coordinate_string(false, y == TinyGPS::GPS_INVALID_ANGLE ? 0 : y, lon);
  dtostrf(faltitude == TinyGPS::GPS_INVALID_F_ALTITUDE ? 0.0 : faltitude, 0, 2, strbuffer);

#if ENABLE_100M_TRUNCATION
  truncate_100m(lat, lon);
#endif

  // prepare the log entry
  memset(buf, 0, LINE_SZ);
  sprintf_P(buf, PSTR("$%s,%04d,%02d-%02d-%02dT%02d:%02d:%02dZ,%ld,%ld,%ld,%c,%s,%c,%s,%c,%s,%c,%ld,%d"),  \
              NANO_HEADER, \
              config.device_id, \
              year, month, day,  \
              hour, minute, second, \
              cpm, \
              cpb, \
              total_count, \
              geiger_status, \
              lat, NS,\
              lon, WE,\
              strbuffer, \
              gps_status, \
              precission == TinyGPS::GPS_INVALID_HDOP ? 0 : precission, \
              nbsat  == TinyGPS::GPS_INVALID_SATELLITES ? 0 : nbsat);

  len = strlen(buf);
  buf[len] = '\0';

  // generate checksum
  chk = checksum(buf+1, len);

  // add checksum to end of line before sending
  if (chk < 16)
    sprintf_P(buf + len, PSTR("*0%X"), (int)chk);
  else
    sprintf_P(buf + len, PSTR("*%X"), (int)chk);
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

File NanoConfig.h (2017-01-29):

#ifndef _NANO_CONFIG_H_
#define _NANO_CONFIG_H_

//
// bGeigie Nano definitions
//

#define NANO_DEVICE_ID         210
#define NANO_VERSION       "1.0.2"
#define NANO_HEADER        "BNRDD"
#define NANO_CPM_FACTOR        334
#define NANO_BQM2_FACTOR        37

//
// Enable or Disable features
//

#define ENABLE_DEBUG             1
#define ENABLE_DIAGNOSTIC        0
#define ENABLE_SSD1306           1
#define ENABLE_SOFTGPS           1
#define ENABLE_STATIC_GPS        0
#define ENABLE_HARDWARE_COUNTER  0
#define ENABLE_OPENLOG           1
#define ENABLE_WAIT_GPS_FOR_LOG  0
#define ENABLE_GPS_NMEA_LOG      0
#define ENABLE_100M_TRUNCATION   0
#define ENABLE_MEDIATEK          1
#define ENABLE_SKYTRAQ           0
#define ENABLE_EEPROM_DOSE       1
#define ENABLE_LND_DEADTIME      1 // enable dead-time compensation for LND7317
#define ENABLE_GEIGIE_SWITCH     0 // switch between bGeigie and xGeigie type
#define ENABLE_NANOKIT_PIN       1 // use the nano kit configuration

#if ENABLE_SSD1306 // high memory usage (avoid logs)
#undef ENABLE_DEBUG // disable debug log output
#endif

//
// Pins definition
//

#if ENABLE_NANOKIT_PIN
  #warning NANO KIT with OLED screen used !
  #define OLED_SPI_MODE // SPI mode enabled
  #define OLED_CLK 7
  #define OLED_DATA 6
  #define OLED_DC 5
  #define OLED_CS 4
  #define OLED_RESET 3
  #define GPS_RX_PIN 8
  #define GPS_TX_PIN 9
  #define OPENLOG_RX_PIN 10
  #define OPENLOG_TX_PIN 11
  #define OPENLOG_RST_PIN 12
#else
#if ENABLE_HARDWARE_COUNTER
  // Pin assignment for version 1.0.1
  #warning Hardware counter is used !
  #define OLED_RESET 4
  #define GPS_RX_PIN 6
  #define GPS_TX_PIN 7
  #define OPENLOG_RX_PIN 8
  #define OPENLOG_TX_PIN 9
  #define OPENLOG_RST_PIN 10
#else
  // Old Pin assignment for version 1.0.0
  #warning Interrupt counter is used !
  #define OLED_RESET 4
  #define GPS_RX_PIN 5
  #define GPS_TX_PIN 6
  #define OPENLOG_RX_PIN 7
  #define OPENLOG_TX_PIN 8
  #define OPENLOG_RST_PIN 9
#endif
#endif

#define GPS_LED_PIN 13

// HardwareCounter pin
// the timer1 pin on the 328p is D5
#define HARDWARE_COUNTER_TIMER1 5

// InterruptCounter pin
// 0 = D2, 1 = D3
#define INTERRUPT_COUNTER_PIN 0

// bGeigie <-> xGeigie switch pin
#define GEIGIE_TYPE_PIN A0
#define GEIGIE_TYPE_THRESHOLD 500

// Voltage divider
// GND -- R2 --A7 -- R1 -- VCC
// https://en.wikipedia.org/wiki/Voltage_divider
#define VOLTAGE_PIN A7
#define VOLTAGE_R1 9100
#define VOLTAGE_R2 1000

#endif

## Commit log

2012-12-23 V 1.03
    Updated libraries, display GPS status decimal and graphically the same
    as rest of display, battery status is correct 0.35V on FIO A7 is
    displaying empty and 0.42V displays full.
    [NanoConfig.h, NanoSetup.h, bGeigieNano.ino]
2012-12-23 Setup updated to correct version number
    [NanoConfig.h]
2017-01-29 Added bGeigieNanoKit 1.1r4 files
    [PelicanHolder5.stl, Wireless charger EJ.skp, Wireless charger EJ~.skp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]

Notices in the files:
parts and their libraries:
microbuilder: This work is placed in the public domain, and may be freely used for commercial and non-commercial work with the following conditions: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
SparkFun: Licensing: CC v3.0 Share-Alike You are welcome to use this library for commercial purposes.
